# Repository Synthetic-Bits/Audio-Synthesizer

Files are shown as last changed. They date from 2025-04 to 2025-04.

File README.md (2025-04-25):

# MIDI Digital Synthesizer

The MIDI Digital Synthesizer is an embedded system capable of interpreting MIDI input signals and synthesizing the audio for the MIDI input. The project was developed as a final project for the University of Utah's ECE 5780: Embedded Systems class. While originally planned to be developed on an STM32F072 Discover board, the system now only works with a STM32H533RE NUCLEO board due to limitation's with the Discovery's flash memory as well as clock speed.

Code for the STM32F072 is present within this repository however, it should be noted that this code hasn't been integrated together and thus, doesn't really work in a cohesive system. That said, the code did represent effort that the Synthetic Bits put in to creating this project and thus, was included in this repository.

## Group Members

- Kenneth Gordon
- Bryant Watson
- Hayoung Im
- Adrian Sucahyo

## Features

The MIDI Digital Synthesizer has the following features:

### Hardware

Microcontroller:
 - STM32H533RE (NUCLEO)

Channels:
 - 7 PWM Channels
     - Sine
     - Triangle
     - Ramp
     - Square
 - 1 DAC
     - Noise

Individual Channel Control:
 - Gain Control
 - Toggleable Low Pass Filter

Master Control:
 - Master Volume Control

Output Speaker Driver:
 - LM1875 Based Class AB Amplifier
 - Up to 20 Watts Driver Capability

### Software

MIDI Interface:
 - MIDI Input
 - MIDI Output

Configurable Channel Waveforms
 - Sine
 - Triangle
 - Ramp
 - Square
 - Noise (restricted to channel 8)

Configurable Voice Channels
- Channels 1-7 capable of 8 voices
- Channels 8 capable of 1 voice

## System Block Diagram

### Software Block Diagram
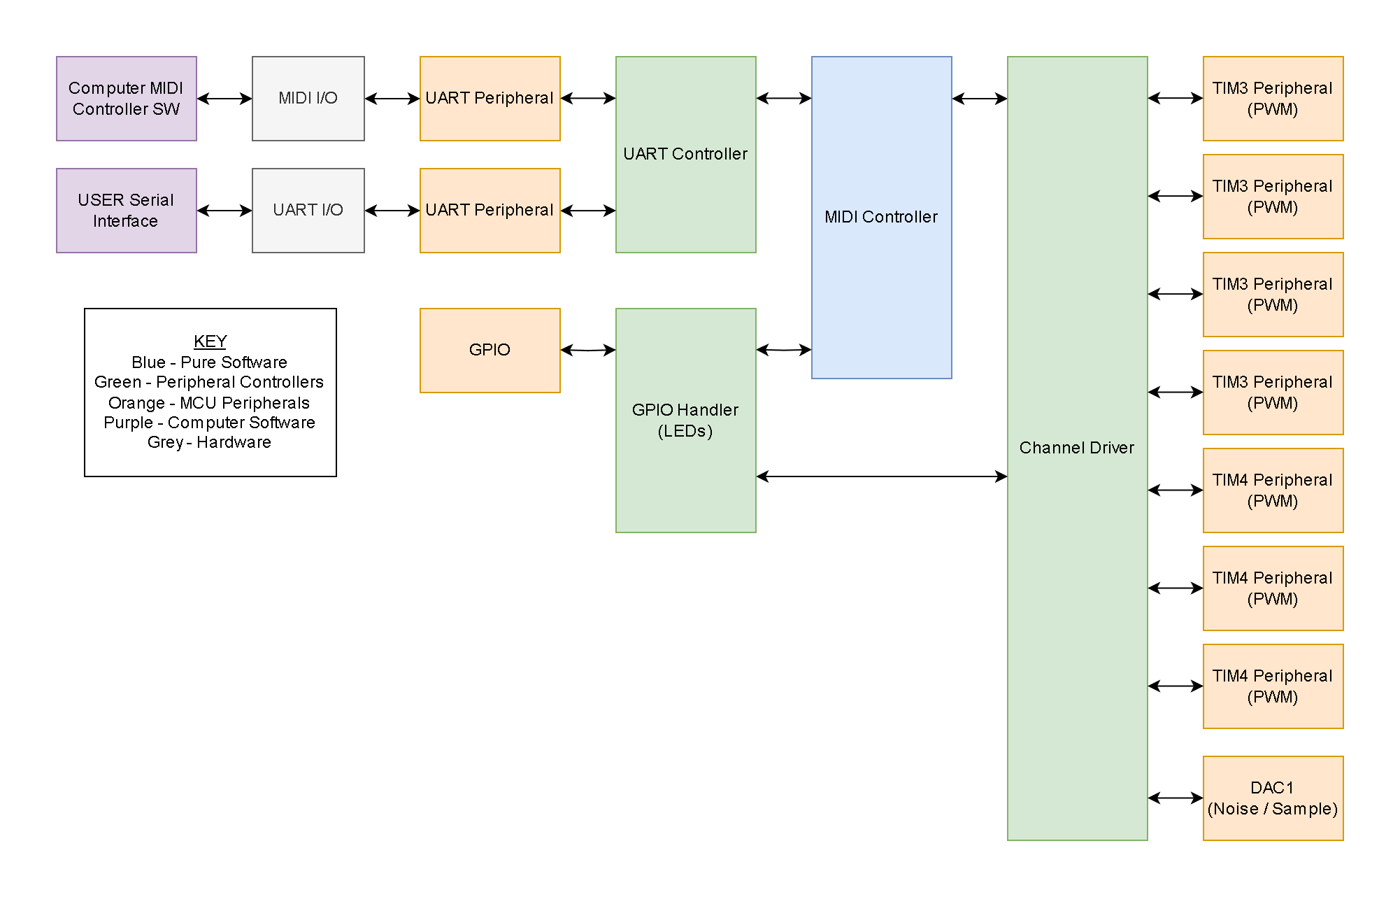
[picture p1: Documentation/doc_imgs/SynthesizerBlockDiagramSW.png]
Software Block Diagram


### Hardware Block Diagram
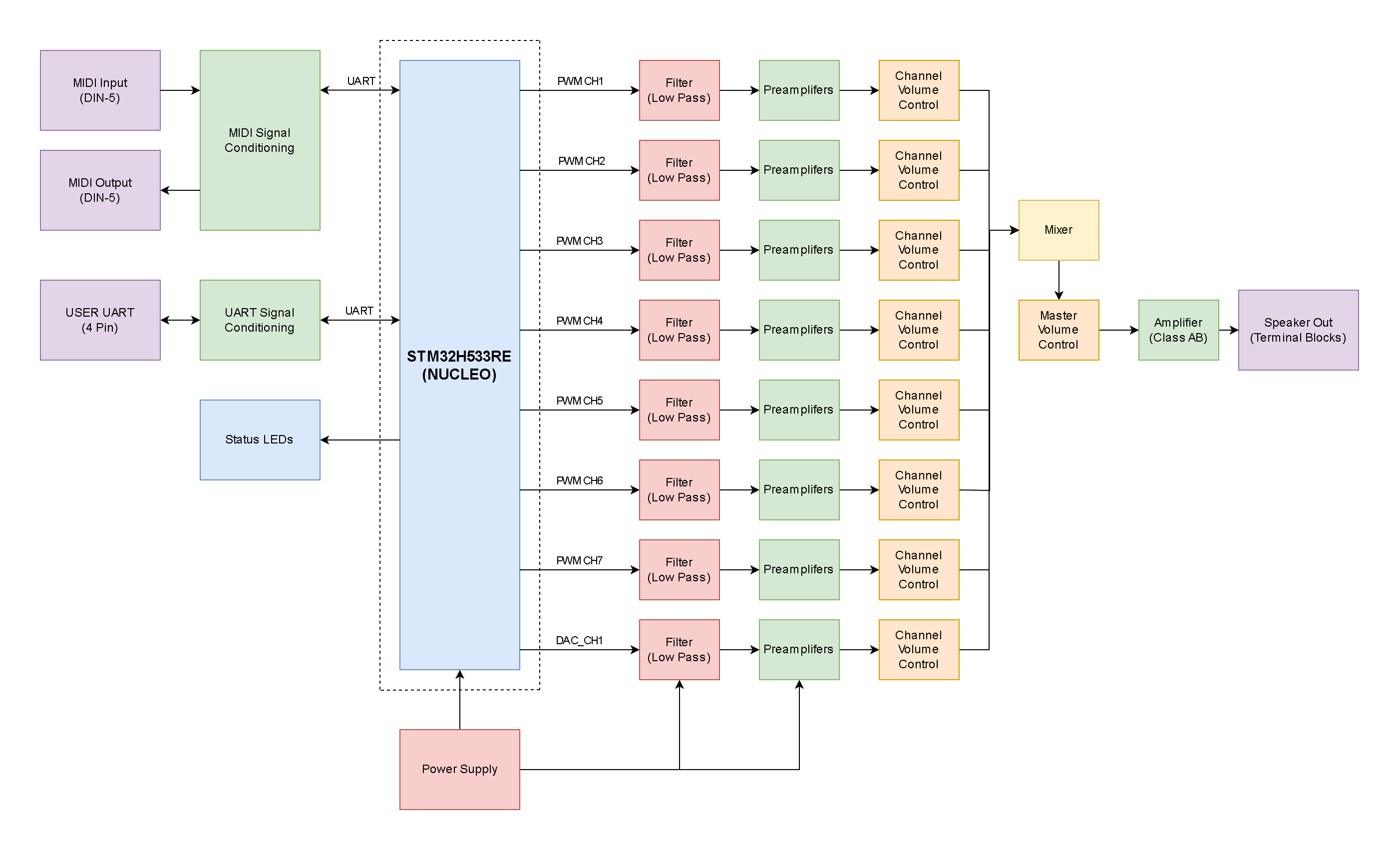
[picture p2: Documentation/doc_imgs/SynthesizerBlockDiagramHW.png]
Hardware Block Diagram


## Setup Guide

1. Put the STM32H533RE (NUCLEO) board (white) on the synthesizer PCB (black) as seen in the below diagrams.
2. Make sure that the jumper cable on the STM32H533RE (NUCLEO) board is set to the E5V to use external power for the board and PCB system.
3. Connect the +15V, GND, -15V, GND from the power supply to the board. Ensure that the power supply is off and to double check wiring is correct, before turning it on.
4. Connect an 8 Ohm speaker to the board.
5. Configure your low-pass filters as desired, per channel.
    - It's recommended to turn off the volume of each channel and set the master to 50%. 
    - Mix the audio as desired by turning up the volume per channel.
6. Connect the MIDI input to the PCB (either with a MIDI-compliant devices or through the pin headers)
    - If a computer is being used to stream MIDI over UART, you can use the provided Python code to stream a MIDI file to the synthesizer. See the below diagram for what pins should be connected.
7. Flash the NUCLEO board using the USB-C STLINK connector.
8. Send your MIDI input to the board. 
    - Mix each of the channels as well as the master channel as desired.
9. _Caution_, the class AB amplifier gets really hot, really quickly. Don't burn yourself or the board! 
    - It is highly recommended to have a large heat sink.

## Board 

### Front Panel

The leftmost connector on the board is the 8 Ohm speaker connector. The left port of this connector is the negative out and the right port is positive out. Refer to the figures above for wire connections.

The middle four connectors on the board control the positive and negative voltage inputs. The connector ports have the following order: GND, -15V, GND, and +15V. 

The rightmost two connectors are the MIDI IN and MIDI OUT connectors. The MIDI IN is used for sending midi commands to the microcontroller for synthesis. The MIDI IN line can connect to a compatible keyboard or computer for sound synthesis. The MIDI OUT is current not used but was included as future code can be written to send MIDI data to other devices from the synthesizer.

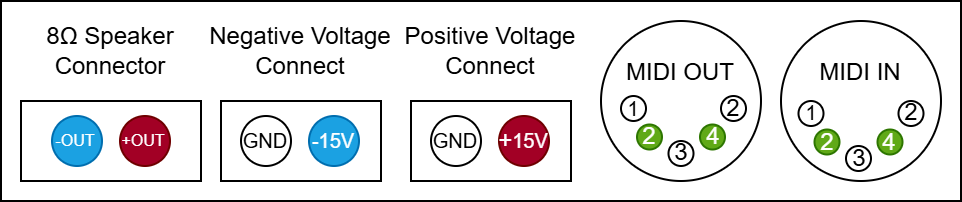
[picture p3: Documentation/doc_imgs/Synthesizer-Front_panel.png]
Front Panel Diagram


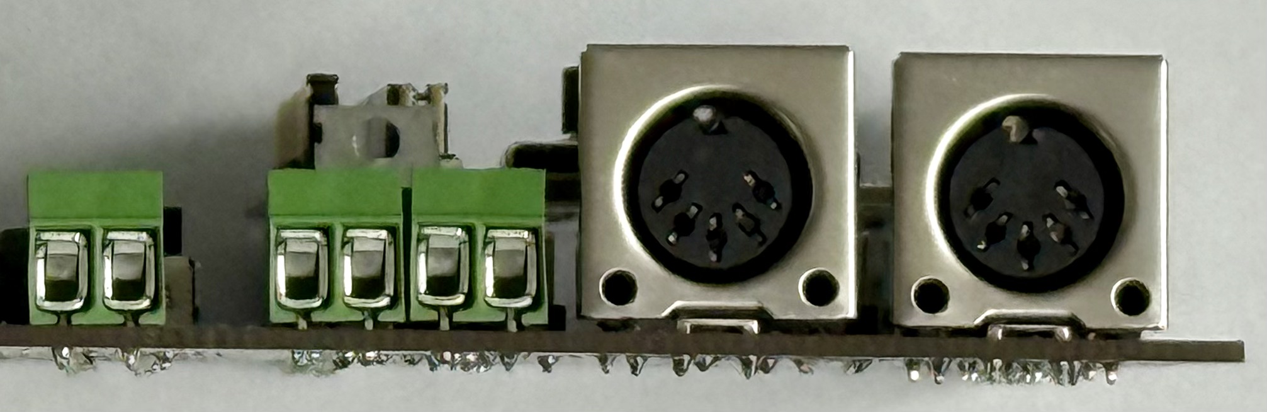
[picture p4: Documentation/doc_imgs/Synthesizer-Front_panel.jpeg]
Front Panel Image


### Top Down

The rightmost device is the the microcontroller board.  This board connects with the main synthesizer board. The blue dots are where a jumper is set.  The E5V connector is used to let the board know to use the external power. All other jumpers are standard and come with the NUCLEO board and the synthesizer board. The NUCLEO board contains a reset button to reset the program and a User button that is currently not used for the synthesizer. Furthermore, the programming for the NUCLEO board uses a USB type C connector on the bottom of the STM32 board. If the user wants to use USB power for testing or MIDI-OUT the user can change the jumper to 5V-STLINK.

The top left section of the board contains the modules for channels 1-8. Each module consists of a low-pass filter and amplifier buffer. The ON/OFF switch controls the low-pass filter. There is a volume nob that uses a potentiometer to control the channel's volume. If the more expensive potentiometers are not available, cheap potentiometers can be used. If cheaper potentiometers are used, the jumper must be moved down. 

The board also has a master channel that mixes and mixes the eight synthesizer channels. The master channel also contains a volume nob using a potentiometer.

There are pins on the main synthesizer board not mentioned above (such as the pins near the capacitors near the +15V and -15V.)  These pins are used for debugging the board.

On the bottom right of the synthesizer board, there are four pins near the MIDI IN that can also be used to send MIDI data from a computer using MIDI-over-UART. These pins are labeled 3V, RX, TX, and GND.

Front Panel Diagram

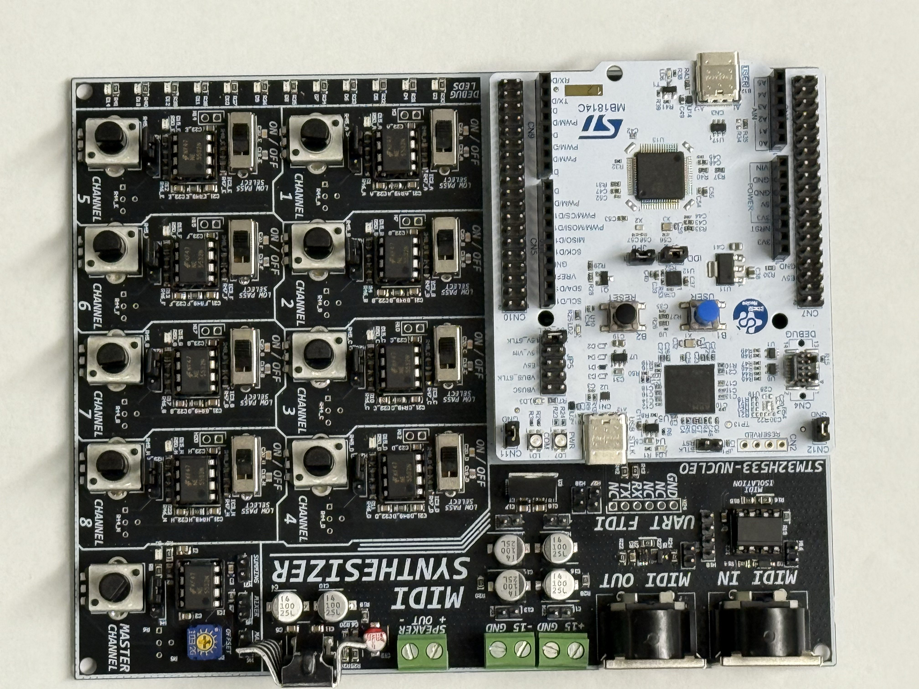
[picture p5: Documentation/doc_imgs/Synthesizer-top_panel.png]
Front Panel Image


## Board Schematic and PCB

### Schematics

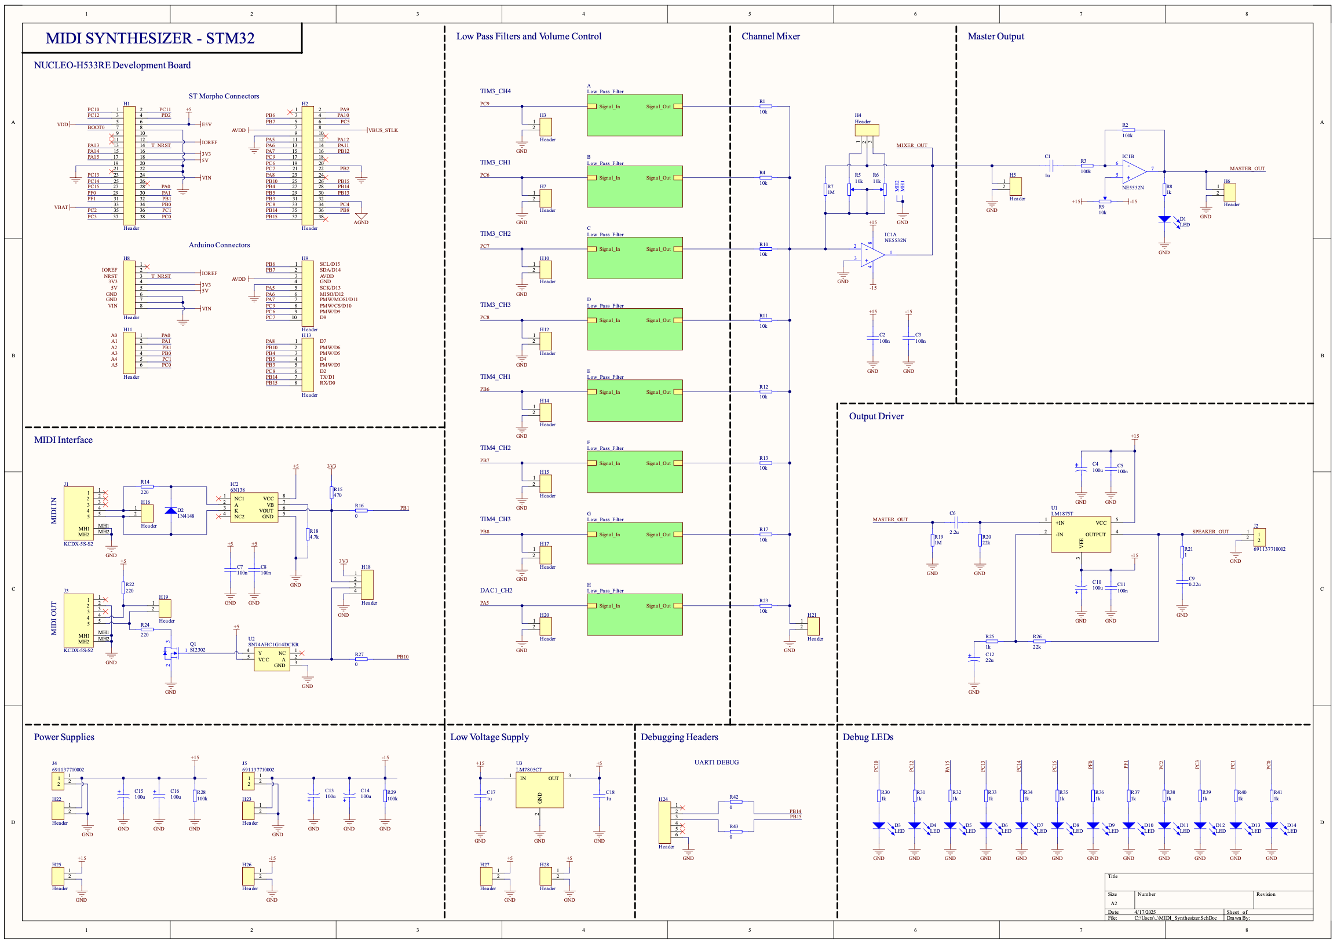
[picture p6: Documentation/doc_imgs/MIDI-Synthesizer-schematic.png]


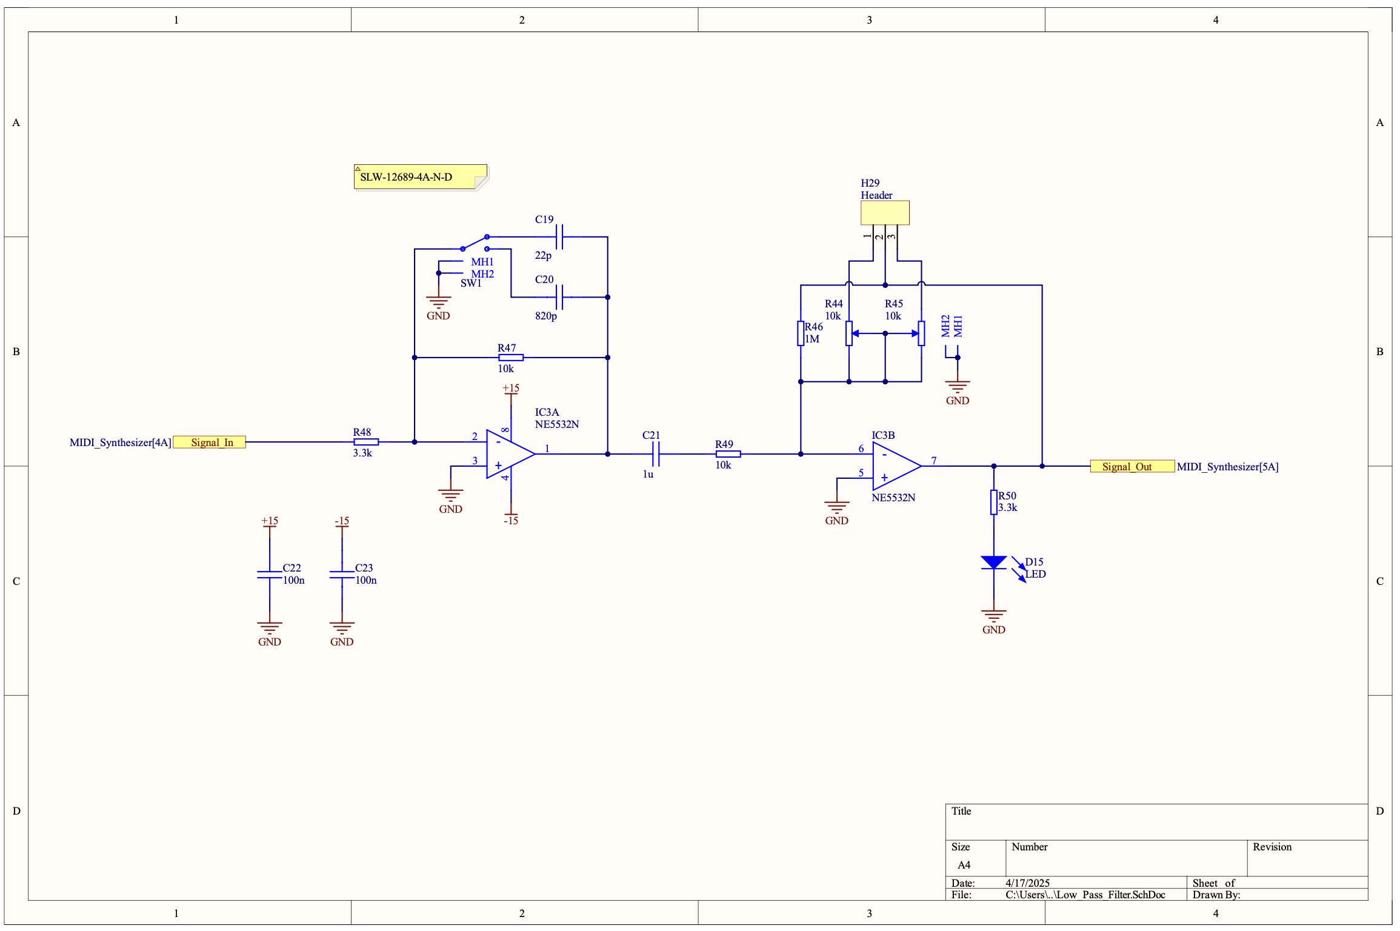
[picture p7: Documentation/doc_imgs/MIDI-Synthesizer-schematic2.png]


### PCB Design

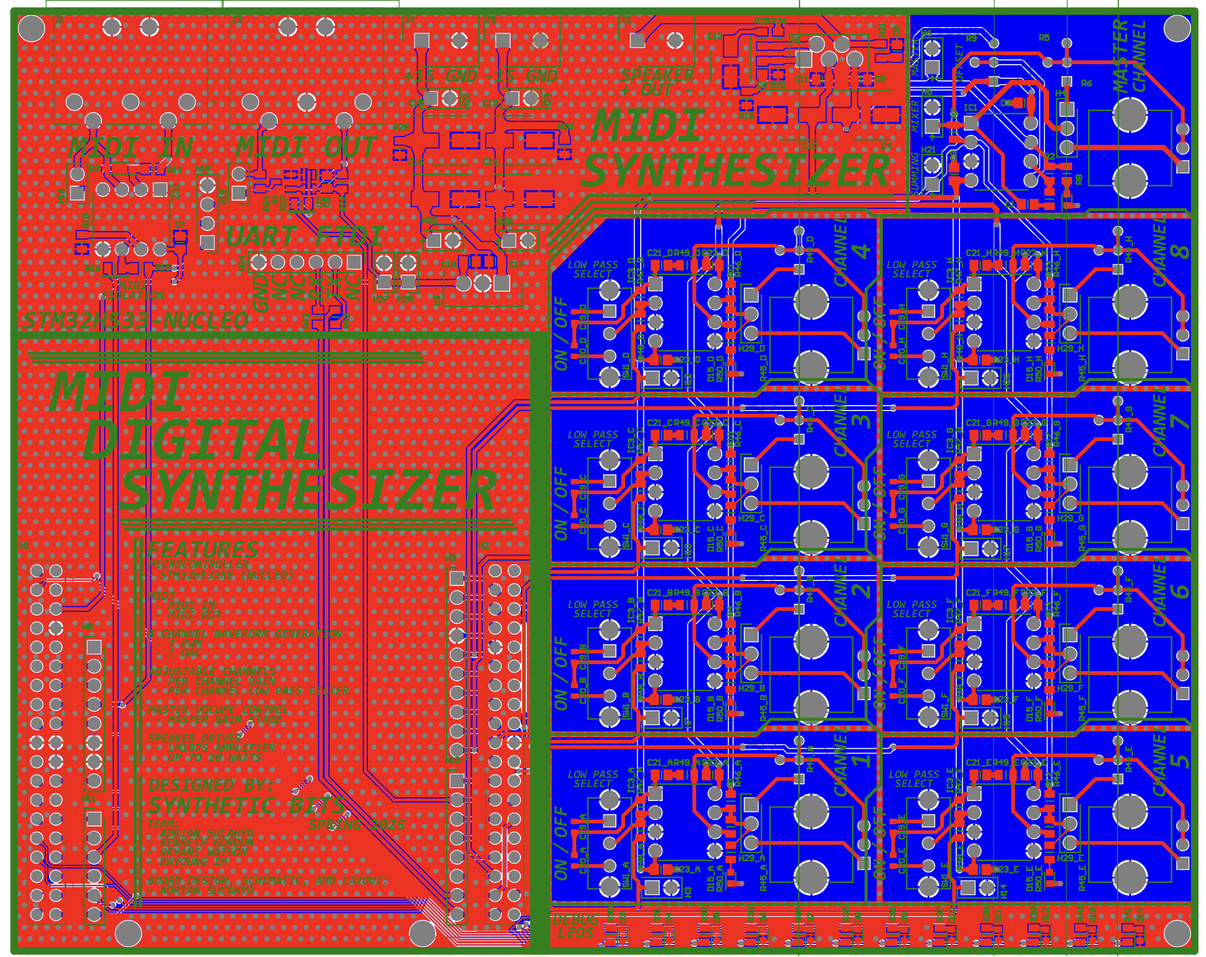
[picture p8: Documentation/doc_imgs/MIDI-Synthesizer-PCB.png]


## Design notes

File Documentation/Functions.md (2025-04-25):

## Src

- `channel_driver.c` – Controls STM32 timers and DAC to generate seven PWM waveform channels plus a noise channel, and provides functions to enable/disable channels, select waveforms, and manage volume and per-voice parameters.  

- `main.c` – Contains the main application entry point for the Audio-Synthesizer.

- `midi.c` – Parses incoming MIDI bytes, decodes MIDI events (note on/off, control changes, pitch bend), and drives the audio channels via the channel driver API.  

- `rcc.c` – Offers simple functions to enable RCC clocks for GPIOA–C, TIM2/3/4, DAC1, and USART1/3 on the STM32H5.  

- `sample_timer.c` – Configures TIM2 as the sample-rate timer and invokes a user-registered callback on each tick to update audio output.  

- `stm32h5xx_hal_msp.c` – Implements the HAL MSP init/de-init hooks, setting up system-level clocks, interrupt priorities, and debug interfaces.  

- `stm32h5xx_it.c` – Defines default ISR handlers for Cortex faults, SysTick, and peripheral interrupts, calling HAL or BSP callbacks as needed.

- `syscalls.c` – Provides minimal Newlib syscall stubs (_read, _write, _open) for bare-metal STM32, routing standard I/O through weak `__io_putchar`/`__io_getchar` hooks.  

- `sysmem.c` – Implements the `_sbrk()` syscall to grow the heap for `malloc` and friends, using linker symbols to prevent heap/stack collision. 

- `system_setup.c` – Implements the Error_Handler loop, configures the system clock (CSI + PLL, bus dividers, flash delay), initializes the instruction cache, and provides a full-assert failure hook.  

- `system_stm32h5xx.c` – Sets up the Error_Handler, system clock (PLL/CSI) and bus dividers, and initializes the instruction cache.  

- `uart.c` – Configures USART1 for user console I/O and USART3 for MIDI, implements interrupt-driven receive plus blocking send/receive routines, and offers a `printu()` helper for easy UART printing.

## Samples

- `attack_base.h` - Defines a 1024-entry short lookup table for the attack curve of the ADSR envelope for the synthesizer.

- `decay_base.h` - Defines a 1024-entry short lookup table for the decay portion of the ADSR envelope for the synthesizer.

- `modulation_base.h` - Defines a 16384-entry short lookup table for the modulation of the ADSR envelope for the synthesizer.

- `ramp_base.h` - Defines a 1024-entry unsigned short lookup table (generated from MATLAB) for the ramp waveform.

- `sine_base.h` - Defines a 1024-entry unsigned short lookup table (generated from MATLAB) for the sine waveform.

- `square_base.h` - Defines a 1024-entry unsigned short lookup table (generated from MATLAB) for the square waveform.

- `trig_base.h` - Defines a 1024-entry unsigned short lookup table (generated from MATLAB) for the trig waveform.

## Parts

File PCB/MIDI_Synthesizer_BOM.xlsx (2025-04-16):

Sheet: Assembly
Comment | Description | Designator | Quantity | Required QTY | To Order | Notes | Ordered
1u | Non Polarized Capacitor | C1, C17, C18, C21_A, C21_B, C21_C, C21_D, C21_E, C21_F, C21_G, C21_H | 11 | 44 | Yes | 50V | 100
100n | Non Polarized Capacitor | C2, C3, C5, C7, C8, C11, C22_A, C22_B, C22_C, C22_D, C22_E, C22_F, C22_G, C22_H, C23_A, C23_B, C23_C, C23_D, C23_E, C23_F, C23_G, C23_H | 22 | 88 | No
100u | Polarized Capacitor | C4, C10, C13, C14, C15, C16 | 6 | 24 | Yes | 50V | 30
2.2u | Polarized Capacitor | C6 | 1 | 4 | Yes | 50V | 10
0.22u | Polarized Capacitor | C9 | 1 | 4 | Yes | 50V | 25
22u | Polarized Capacitor | C12 | 1 | 4 | Yes | 50V | 10
22p | Non Polarized Capacitor | C19_A, C19_B, C19_C, C19_D, C19_E, C19_F, C19_G, C19_H | 8 | 32 | Yes | 50V | 100
820p | Non Polarized Capacitor | C20_A, C20_B, C20_C, C20_D, C20_E, C20_F, C20_G, C20_H | 8 | 32 | Yes | 50V | 100
LED | General Purpose LED | D1, D3, D4, D5, D6, D7, D8, D9, D10, D11, D12, D13, D14, D15_A, D15_B, D15_C, D15_D, D15_E, D15_F, D15_G, D15_H | 21 | 84 | No
1N4148 | 1N4148 General Purpose Switching Diode | D2 | 1 | 4 | No
Header | 38-Pin 2 Row Header | H1, H2 | 2 | 8 | Yes | Amazon
Header | 2-Pin Header | H3, H5, H6, H7, H10, H12, H14, H15, H16, H17, H19, H20, H21, H22, H23, H25, H26, H27, H28 | 19 | 76 | No
Header | 3-Pin Header | H4, H29_A, H29_B, H29_C, H29_D, H29_E, H29_F, H29_G, H29_H | 9 | 36 | No
Header | 8-Pin Header | H8, H13 | 2 | 8 | No
Header | 10-Pin Header | H9 | 1 | 4 | No
Header | 6-Pin Header | H11, H24 | 2 | 8 | No
Header | 4-Pin Header | H18 | 1 | 4 | No
NE5532N | Integrated Circuit | IC1, IC3_A, IC3_B, IC3_C, IC3_D, IC3_E, IC3_F, IC3_G, IC3_H | 9 | 36 | Yes | Stockroom
6N138 | Integrated Circuit | IC2 | 1 | 4 | Yes |  | 10
KCDX-5S-S2 | Connector | J1, J3 | 2 | 8 | Yes |  | 10
691137710002 | Connector | J2, J4, J5 | 3 | 12 | Yes | IEEE | 0
SI2302 | General Purpose N-Channel MOSFET | Q1 | 1 | 4 | No
10k | Resistor | R1, R4, R10, R11, R12, R13, R17, R23, R47_A, R47_B, R47_C, R47_D, R47_E, R47_F, R47_G, R47_H, R49_A, R49_B, R49_C, R49_D, R49_E, R49_F, R49_G, R49_H | 24 | 96 | No
100k | Resistor | R2, R3, R28, R29 | 4 | 16 | No
10k | Potentionmeter | R5, R9, R44_A, R44_B, R44_C, R44_D, R44_E, R44_F, R44_G, R44_H | 10 | 40 | Yes | Stockroom
10k | Potentionmeter | R6, R45_A, R45_B, R45_C, R45_D, R45_E, R45_F, R45_G, R45_H | 9 | 36 | Yes |  | 40
1M | Resistor | R7, R19, R46_A, R46_B, R46_C, R46_D, R46_E, R46_F, R46_G, R46_H | 10 | 40 | No
1k | Resistor | R8, R30, R31, R32, R33, R34, R35, R36, R37, R38, R39, R40, R41 | 13 | 52 | No
220 | Resistor | R14, R22, R24 | 3 | 12 | Yes |  | 100
470 | Resistor | R15 | 1 | 4 | No
0 | Resistor | R16, R27, R42, R43 | 4 | 16 | No
4.7k | Resistor | R18 | 1 | 4 | No
22k | Resistor | R20, R26 | 2 | 8 | Yes |  | 100
1 | Resistor | R21 | 1 | 4 | Yes |  | 100
1k | Resistor | R25 | 1 | 4 | No
3.3k | Resistor | R48_A, R48_B, R48_C, R48_D, R48_E, R48_F, R48_G, R48_H | 8 | 32 | No
3.3k | Resistor | R50_A, R50_B, R50_C, R50_D, R50_E, R50_F, R50_G, R50_H | 8 | 32 | No
Slide Switch 4 | Slide Switch | SW1_A, SW1_B, SW1_C, SW1_D, SW1_E, SW1_F, SW1_G, SW1_H | 8 | 32 | Yes |  | 40
LM1875T | Integrated Circuit | U1 | 1 | 4 | Yes |  | 6
SN74AHC1G14DCKR | Integrated Circuit | U2 | 1 | 4 | Yes |  | 10
LM7805CT | Integrated Circuit | U3 | 1 | 4 | Yes | Stockroom

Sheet: Sheet1
Comment | Description | Designator | Quantity | Required QTY | To Order | Notes | Ordered
1u | Non Polarized Capacitor | C1, C17, C18, C21_A, C21_B, C21_C, C21_D, C21_E, C21_F, C21_G, C21_H | 11 | 44 | Yes | 50V | 100
100n | Non Polarized Capacitor | C2, C3, C5, C7, C8, C11, C22_A, C22_B, C22_C, C22_D, C22_E, C22_F, C22_G, C22_H, C23_A, C23_B, C23_C, C23_D, C23_E, C23_F, C23_G, C23_H | 22 | 88 | No
100u | Polarized Capacitor | C4, C10, C13, C14, C15, C16 | 6 | 24 | Yes | 50V | 30
2.2u | Polarized Capacitor | C6 | 1 | 4 | Yes | 50V | 10
0.22u | Polarized Capacitor | C9 | 1 | 4 | Yes | 50V | 25
22u | Polarized Capacitor | C12 | 1 | 4 | Yes | 50V | 10
22p | Non Polarized Capacitor | C19_A, C19_B, C19_C, C19_D, C19_E, C19_F, C19_G, C19_H | 8 | 32 | Yes | 50V | 100
820p | Non Polarized Capacitor | C20_A, C20_B, C20_C, C20_D, C20_E, C20_F, C20_G, C20_H | 8 | 32 | Yes | 50V | 100
LED | General Purpose LED | D1, D3, D4, D5, D6, D7, D8, D9, D10, D11, D12, D13, D14, D15_A, D15_B, D15_C, D15_D, D15_E, D15_F, D15_G, D15_H | 21 | 84 | No
1N4148 | 1N4148 General Purpose Switching Diode | D2 | 1 | 4 | No
Header | 38-Pin 2 Row Header | H1, H2 | 2 | 8 | Yes | Amazon
Header | 2-Pin Header | H3, H5, H6, H7, H10, H12, H14, H15, H16, H17, H19, H20, H21, H22, H23, H25, H26, H27, H28 | 19 | 76 | No
Header | 3-Pin Header | H4, H29_A, H29_B, H29_C, H29_D, H29_E, H29_F, H29_G, H29_H | 9 | 36 | No
Header | 8-Pin Header | H8, H13 | 2 | 8 | No
Header | 10-Pin Header | H9 | 1 | 4 | No
Header | 6-Pin Header | H11, H24 | 2 | 8 | No
Header | 4-Pin Header | H18 | 1 | 4 | No
NE5532N | Integrated Circuit | IC1, IC3_A, IC3_B, IC3_C, IC3_D, IC3_E, IC3_F, IC3_G, IC3_H | 9 | 36 | Yes | Stockroom
6N138 | Integrated Circuit | IC2 | 1 | 4 | Yes |  | 10
KCDX-5S-S2 | Connector | J1, J3 | 2 | 8 | Yes |  | 10
691137710002 | Connector | J2, J4, J5 | 3 | 12 | Yes | IEEE | 0
SI2302 | General Purpose N-Channel MOSFET | Q1 | 1 | 4 | No
10k | Resistor | R1, R4, R10, R11, R12, R13, R17, R23, R47_A, R47_B, R47_C, R47_D, R47_E, R47_F, R47_G, R47_H, R49_A, R49_B, R49_C, R49_D, R49_E, R49_F, R49_G, R49_H | 24 | 96 | No
100k | Resistor | R2, R3, R28, R29 | 4 | 16 | No
10k | Potentionmeter | R5, R9, R44_A, R44_B, R44_C, R44_D, R44_E, R44_F, R44_G, R44_H | 10 | 40 | Yes | Stockroom
10k | Potentionmeter | R6, R45_A, R45_B, R45_C, R45_D, R45_E, R45_F, R45_G, R45_H | 9 | 36 | Yes |  | 40
1M | Resistor | R7, R19, R46_A, R46_B, R46_C, R46_D, R46_E, R46_F, R46_G, R46_H | 10 | 40 | No
1k | Resistor | R8, R30, R31, R32, R33, R34, R35, R36, R37, R38, R39, R40, R41 | 13 | 52 | No
220 | Resistor | R14, R22, R24 | 3 | 12 | Yes |  | 100
470 | Resistor | R15 | 1 | 4 | No
0 | Resistor | R16, R27, R42, R43 | 4 | 16 | No
4.7k | Resistor | R18 | 1 | 4 | No
22k | Resistor | R20, R26 | 2 | 8 | Yes |  | 100
1 | Resistor | R21 | 1 | 4 | Yes |  | 100
1k | Resistor | R25 | 1 | 4 | No
3.3k | Resistor | R48_A, R48_B, R48_C, R48_D, R48_E, R48_F, R48_G, R48_H | 8 | 32 | No
3.3k | Resistor | R50_A, R50_B, R50_C, R50_D, R50_E, R50_F, R50_G, R50_H | 8 | 32 | No
Slide Switch 4 | Slide Switch | SW1_A, SW1_B, SW1_C, SW1_D, SW1_E, SW1_F, SW1_G, SW1_H | 8 | 32 | Yes |  | 40
LM1875T | Integrated Circuit | U1 | 1 | 4 | Yes |  | 6
SN74AHC1G14DCKR | Integrated Circuit | U2 | 1 | 4 | Yes |  | 10
LM7805CT | Integrated Circuit | U3 | 1 | 4 | Yes | Stockroom

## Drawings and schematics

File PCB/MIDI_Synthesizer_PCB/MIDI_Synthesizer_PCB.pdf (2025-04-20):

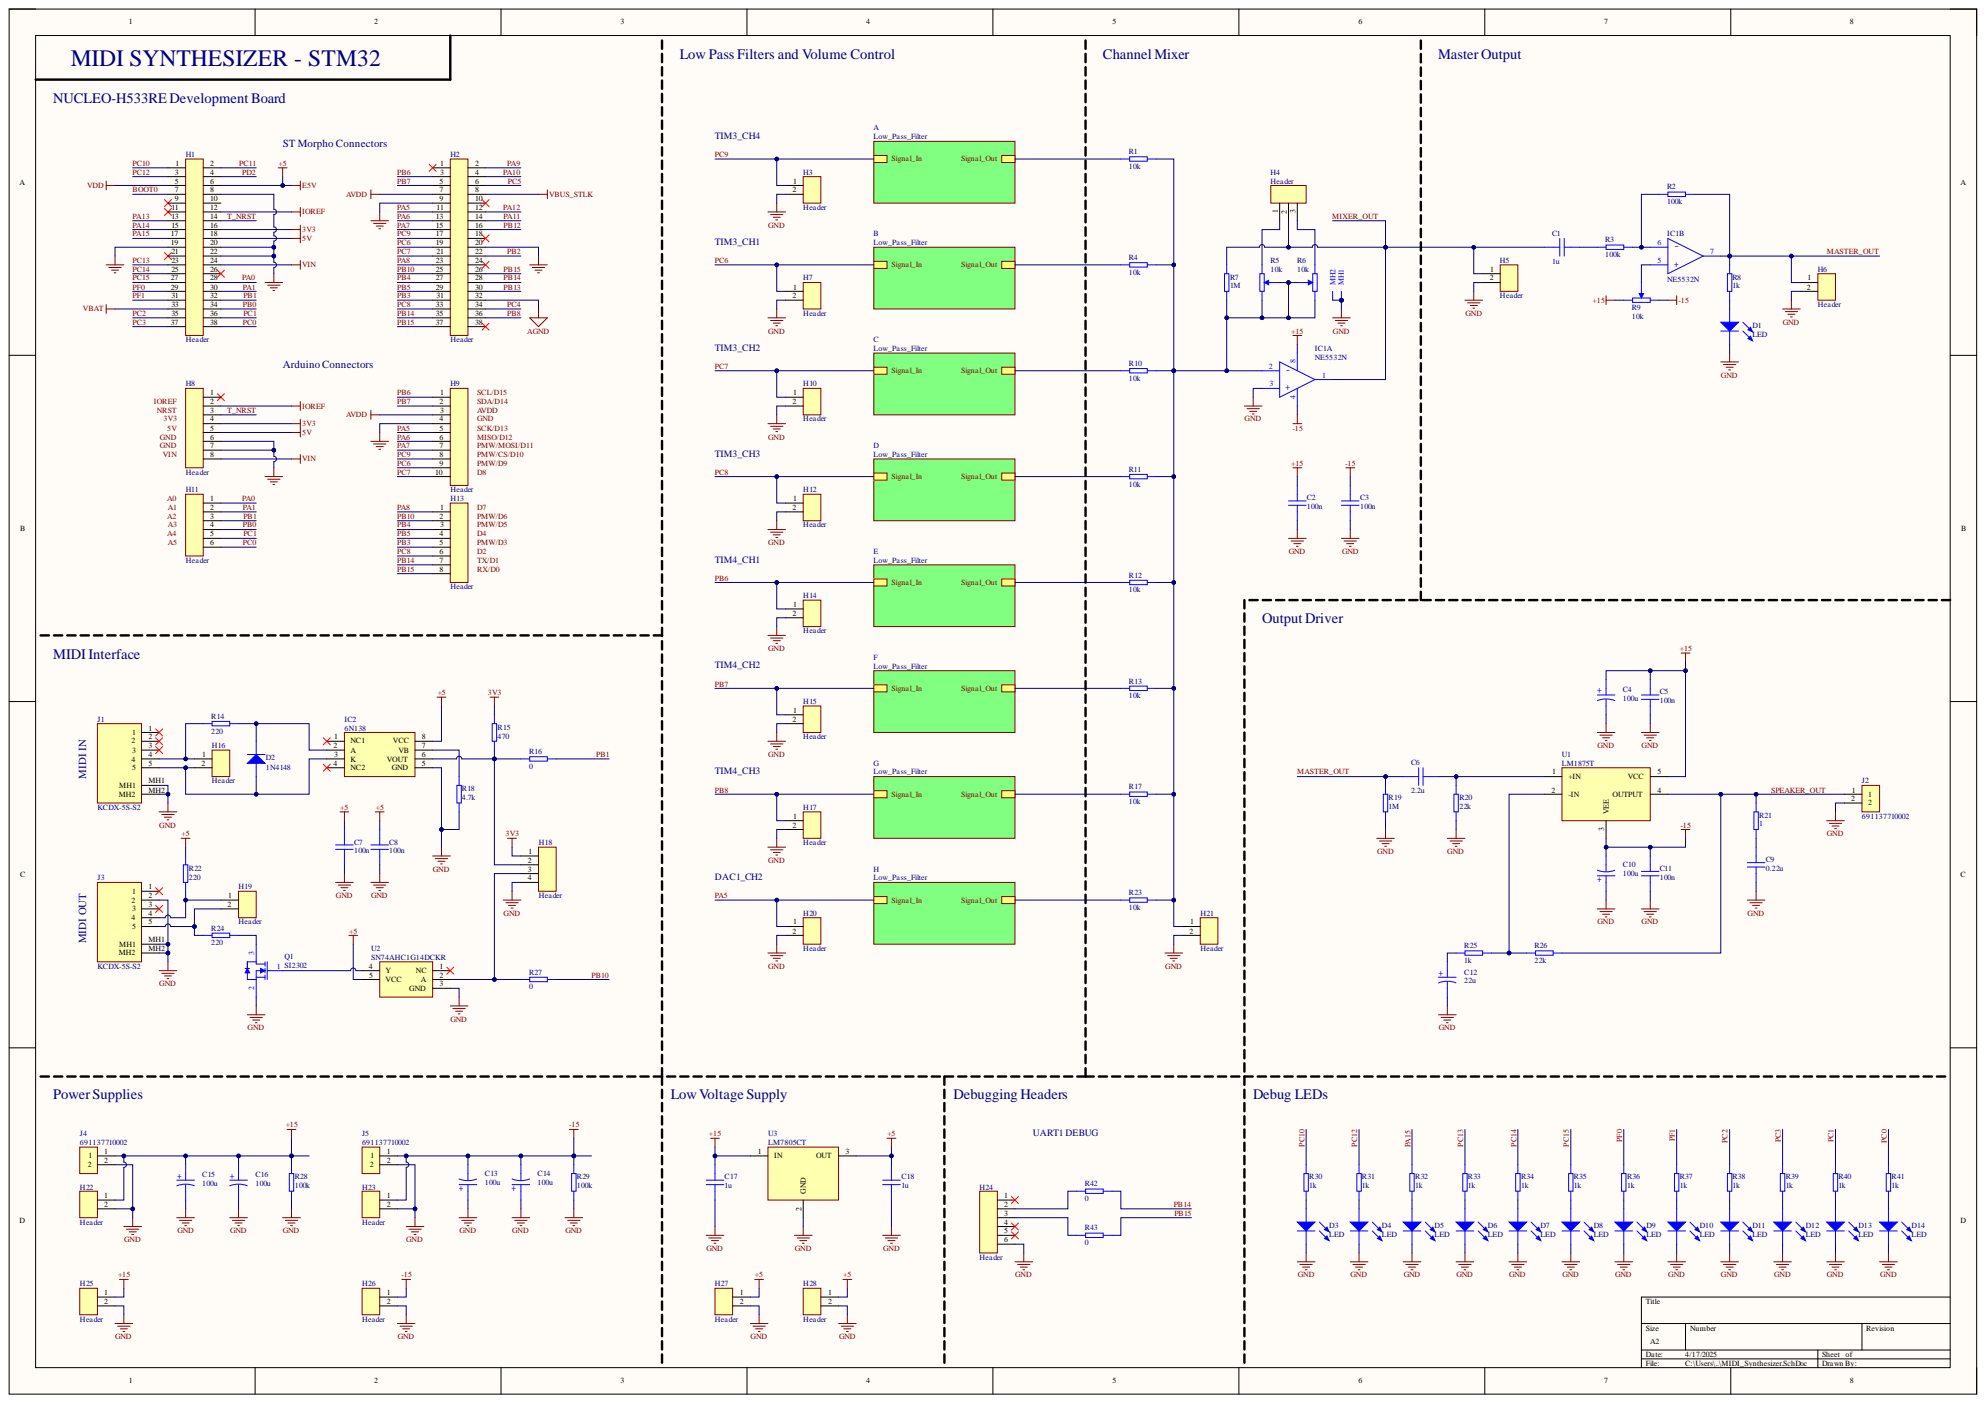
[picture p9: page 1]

Low Pass Filters and Volume Control

MIDI IN MIDI OUT

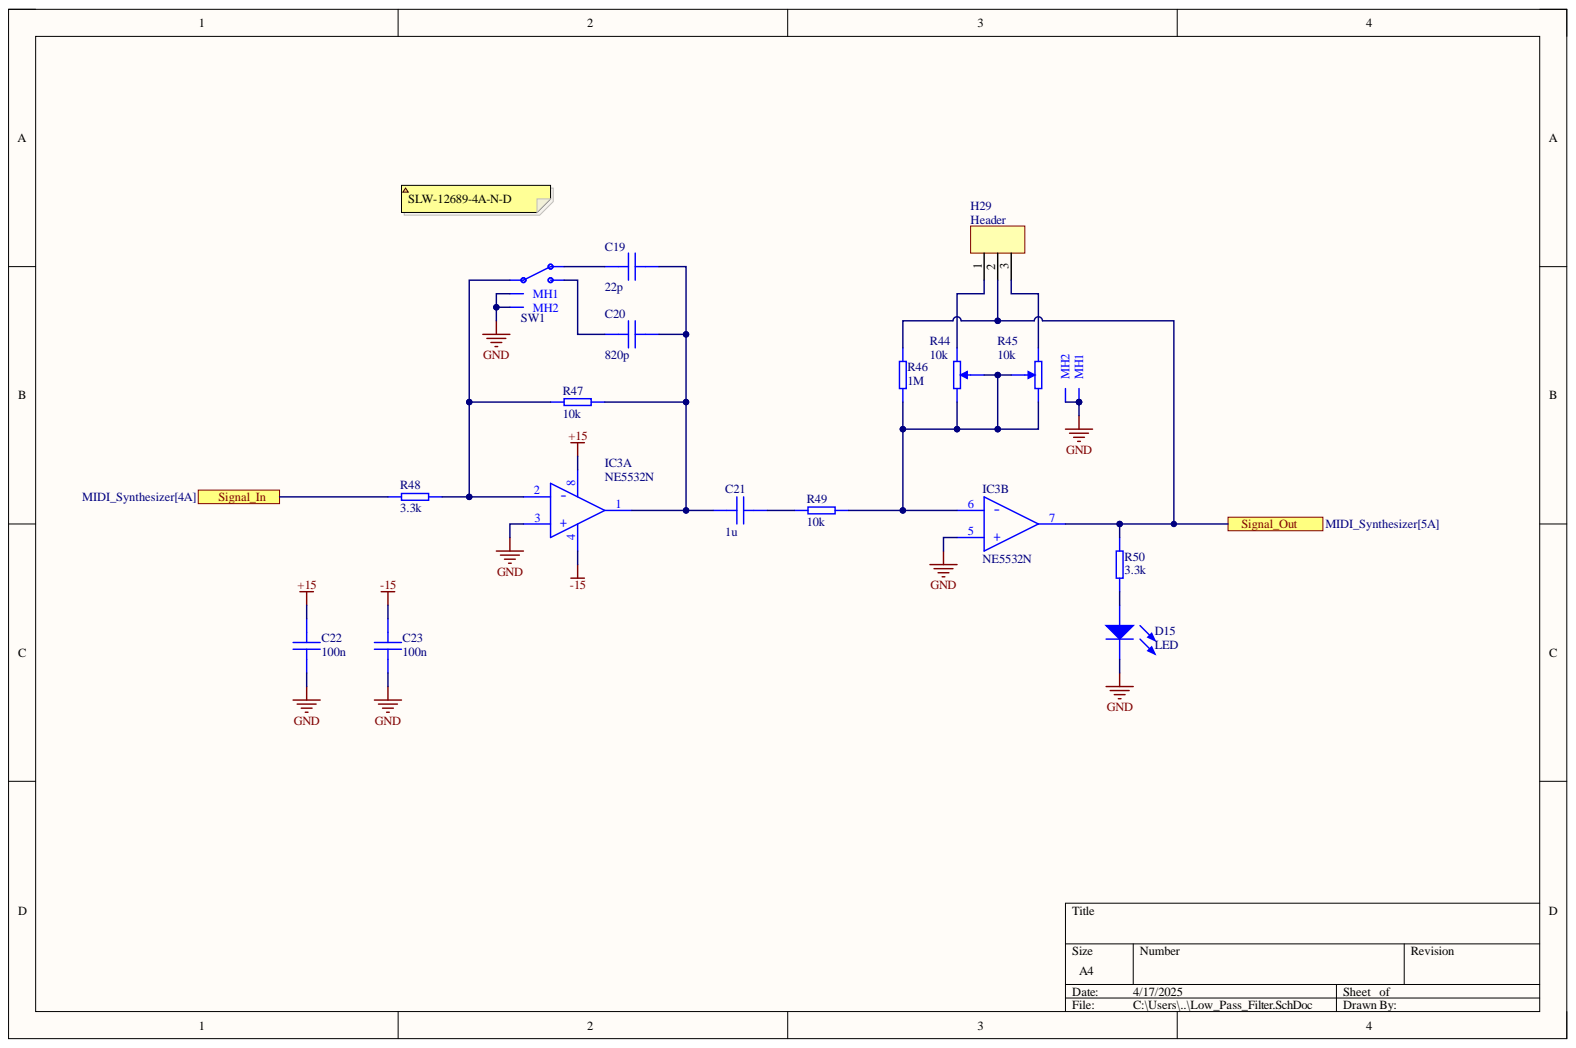
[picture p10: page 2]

Size A4 | Number | Revision

Date: 4/17/2025 | Sheet of
File: C:\Users\..\Low_Pass_Filter.SchDoc | Drawn By:

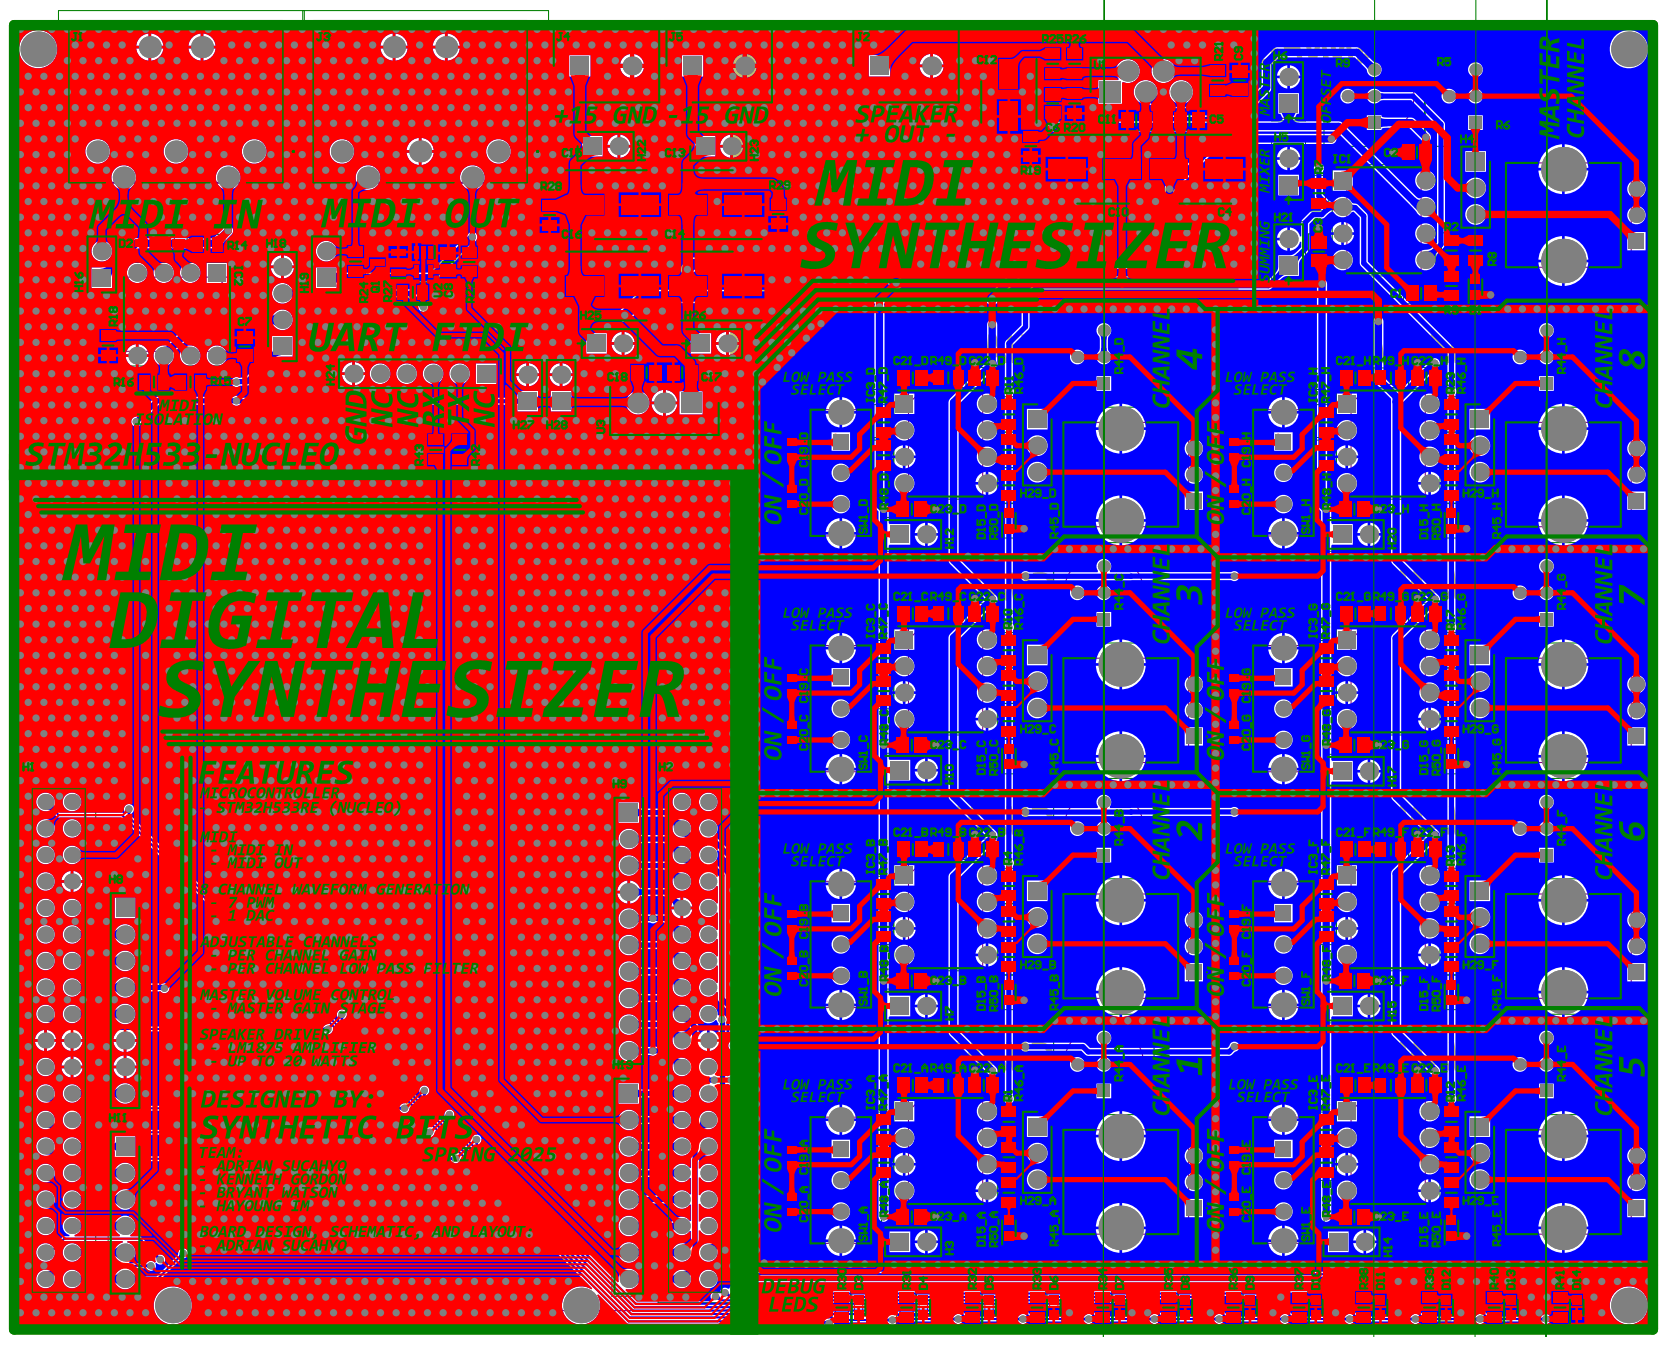
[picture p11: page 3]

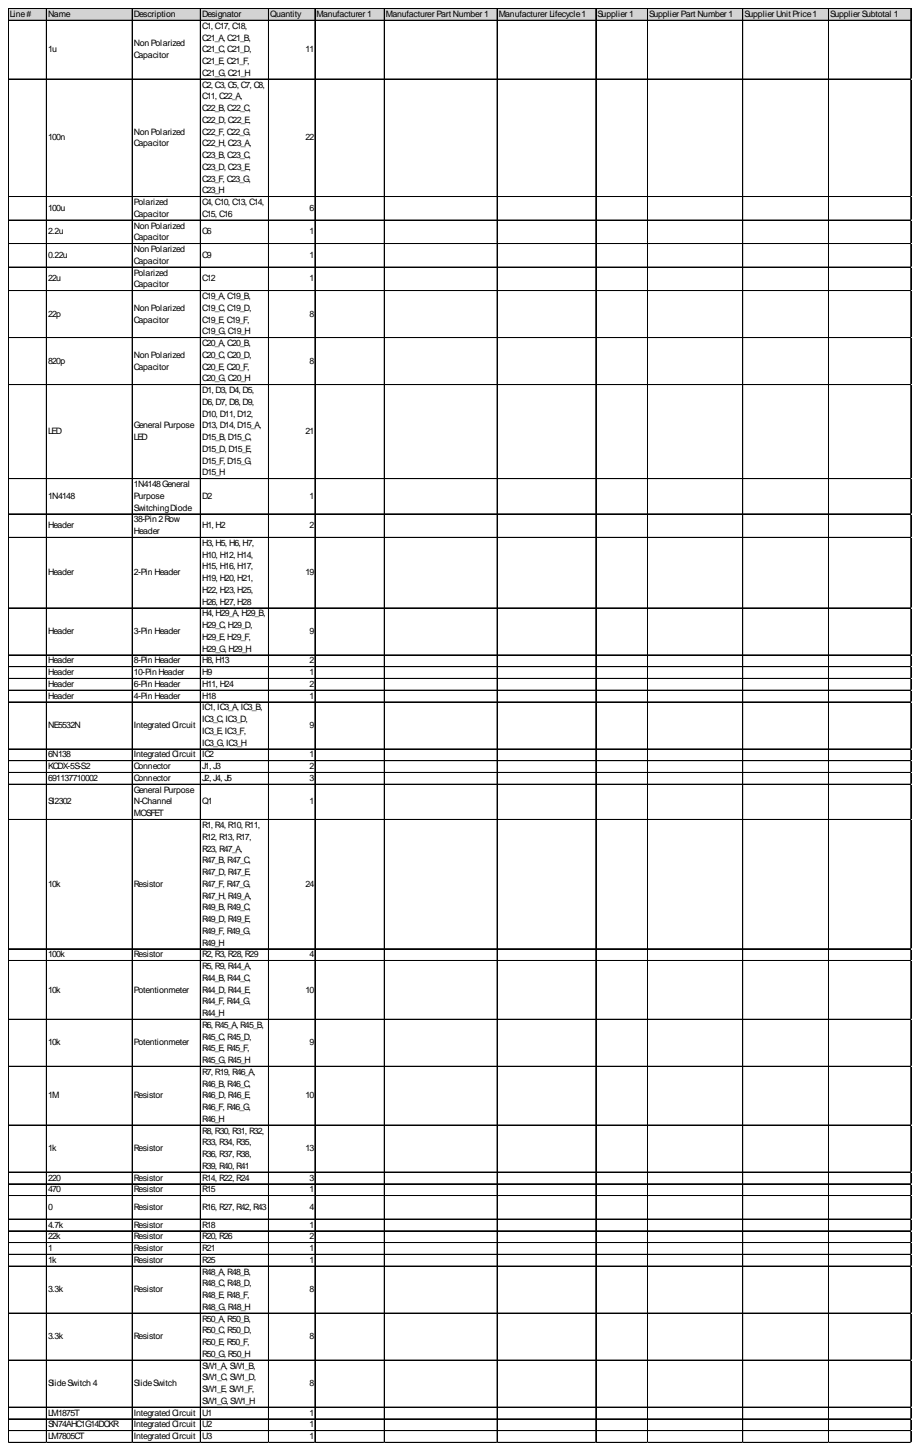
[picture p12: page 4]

Line# | Name | Description | Designator | Quantity | Manufacturer 1 | Manufacturer Part Number 1 | Manufacturer Lifecycle1 | Supplier 1 | Supplier Part Number 1 | Supplier Unit Price1 | Supplier Subtotal 1

1u | Non Polarized Capacitor | C1, C17, C18, C21_A, C21_B, C21_C, C21_D, C21_E, C21_F, C21_G, C21_H | 11

100n | Non Polarized Capacitor | C2, C3, C5, C7, C8, C11, C22_A, C22_B, C22_C, C22_D, C22_E, C22_F, C22_G, C22_H, C23_A, C23_B, C23_C, C23_D, C23_E, C23_F, C23_G, C23_H | 22

100u | Polarized Capacitor | C4, C10, C13, C14, C15, C16 | | 6

2.2u | Non Polarized Capacitor | C6 | | 1

0.22u | Non Polarized Capacitor | C9 | | 1

22u | Polarized Capacitor | C12 | | 1

22p | Non Polarized Capacitor | C19_A, C19_B, C19_C, C19_D, C19_E, C19_F, C19_G, C19_H | | 8

820p | Non Polarized Capacitor | C20_A, C20_B, C20_C, C20_D, C20_E, C20_F, C20_G, C20_H | | 8

LED | General Purpose LED | D1, D3, D4, D5, D6, D7, D8, D9, D10, D11, D12, D13, D14, D15_A, D15_B, D15_C, D15_D, D15_E, D15_F, D15_G, D15_H | 21

1N4148 | 1N4148General Purpose SwitchingDiode | D2 | | 1

Header | 38-Pin 2Row Header | H1, H2 | | 2

Header | 2-Pin Header | H3, H5, H6, H7, H10, H12, H14, H15, H16, H17, H19, H20, H21, H22, H23, H25, H26, H27, H28 | 19

Header | 3-Pin Header | H4, H29_A, H29_B, H29_C, H29_D, H29_E, H29_F, H29_G, H29_H | | 9

Header | 8-Pin Header | H8, H13 | | 2
Header | 10-Pin Header | H9 | | 1
Header | 6-Pin Header | H11, H24 | | 2
Header | 4-Pin Header | H18 | | 1
NE5532N | Integrated Circuit | IC1, IC3_A, IC3_B, IC3_C, IC3_D, IC3_E, IC3_F, IC3_G, IC3_H | | 9

6N138 | Integrated Circuit | IC2 | | 1
KCDX-5S-S2 | Connector | J1, J3 | | 2
691137710002 | Connector | J2, J4, J5 | | 3
SI2302 | General Purpose N-Channel MOSFET | Q1 | | 1

10k | Resistor | R1, R4, R10, R11, R12, R13, R17, R23, R47_A, R47_B, R47_C, R47_D, R47_E, R47_F, R47_G, R47_H, R49_A, R49_B, R49_C, R49_D, R49_E, R49_F, R49_G, R49_H | 24

100k | Resistor | R2, R3, R28, R29 | | 4
10k | Potentionmeter | R5, R9, R44_A, R44_B, R44_C, R44_D, R44_E, R44_F, R44_G, R44_H | 10

10k | Potentionmeter | R6, R45_A, R45_B, R45_C, R45_D, R45_E, R45_F, R45_G, R45_H | | 9

1M | Resistor | R7, R19, R46_A, R46_B, R46_C, R46_D, R46_E, R46_F, R46_G, R46_H | 10

1k | Resistor | R8, R30, R31, R32, R33, R34, R35, R36, R37, R38, R39, R40, R41 | 13

220 | Resistor | R14, R22, R24 | | 3
470 | Resistor | R15 | | 1

0 | Resistor | R16, R27, R42, R43 | | 4

4.7k | Resistor | R18 | | 1
22k | Resistor | R20, R26 | | 2
1 | Resistor | R21 | | 1
1k | Resistor | R25 | | 1
3.3k | Resistor | R48_A, R48_B, R48_C, R48_D, R48_E, R48_F, R48_G, R48_H | | 8

3.3k | Resistor | R50_A, R50_B, R50_C, R50_D, R50_E, R50_F, R50_G, R50_H | | 8

SlideSwitch 4 | SlideSwitch | SW1_A, SW1_B, SW1_C, SW1_D, SW1_E, SW1_F, SW1_G, SW1_H | | 8

LM1875T | Integrated Circuit | U1 | | 1
SN74AHC1G14DCKR | Integrated Circuit | U2 | | 1
LM7805CT | Integrated Circuit | U3 | | 1

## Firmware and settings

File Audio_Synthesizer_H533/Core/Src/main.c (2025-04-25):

/**
 ******************************************************************************
 * @file           : main.c
 * @brief          : Main program body
 * @authors        : Adrian Sucahyo, Kenneth Gordon, Bryant Watson,
 *                   and Hayoung Im
 ******************************************************************************
 * @attention
 *
 * Copyright (c) 2024 STMicroelectronics.
 * All rights reserved.
 *
 * This software is licensed under terms that can be found in the LICENSE file
 * in the root directory of this software component.
 * If no LICENSE file comes with this software, it is provided AS-IS.
 *
 ******************************************************************************
 */

/* Includes ------------------------------------------------------------------*/

#include "config.h"
#include "main.h"
#include "uart.h"
#include "midi.h"
#include <stm32h5xx_hal.h>

/* Private includes ----------------------------------------------------------*/

#include "sample_timer.h"
#include "channel_common.h"
#include "channel_driver.h"

/* Private typedef -----------------------------------------------------------*/

/* Private define ------------------------------------------------------------*/

// Define for configuring the UART tests
#define UART_INTERRUPT_TEST

#define MIDI_UART_SIZE (1024 * 8)

/* Private macro -------------------------------------------------------------*/

/* Private variables ---------------------------------------------------------*/

// UART Global Buffers
extern volatile int global_receive_buffer_index;
extern volatile uint8_t global_receive_buffer[GLOBAL_RECEIVE_BUFFER_SIZE];

// Flag for data received to idle
extern volatile uint8_t midi_data_ready_flag;

// What are these
extern volatile channel_state_t channel1_state, channel2_state, channel3_state, channel4_state, channel5_state, channel6_state, channel7_state, channel8_state;

static const uint16_t baud_rate = 31250;

// Channel Definitions
#define CHANNEL1_WAVE WAVEFORM_SQUARE
#define CHANNEL2_WAVE WAVEFORM_RAMP
#define CHANNEL3_WAVE WAVEFORM_TRIG
#define CHANNEL4_WAVE WAVEFORM_SINE
#define CHANNEL5_WAVE WAVEFORM_SQUARE
#define CHANNEL6_WAVE WAVEFORM_RAMP
#define CHANNEL7_WAVE WAVEFORM_TRIG
#define CHANNEL8_WAVE WAVEFORM_NOISE

/* Private function prototypes -----------------------------------------------*/

// Testing functions for UART
void test_USER_UART(void);
void test_MIDI_UART(void);

// Initialization functions
void init_sample_timer(void);
void init_channel_driver(void);

// Handler for when samples need to be updated
void sample_timer_handler(void);

// Synthesis functions
void midi_processer(void);
void start_audio_synthesis(void);
void stop_audio_synthesis(void);

/* Private user code ---------------------------------------------------------*/

/* ========================================================================== */
/*                                                                            */
/*        Demonstration Functions                                             */
/*                                                                            */
/* ========================================================================== */

/**
 * @brief This function tests the USER_UART peripheral to see if it is working as intended.
 * @param None
 * @retval None.
 */
void test_USER_UART()
{
#ifdef UART_INTERRUPT_TEST
  // Initialize the USER_UART peripheral (interrupt-mode)
  configure_USER_UART(115200, UART_ENABLE_INTERRUPTS, 2);

  // Send info using USER_UART
  send_USER_UART("Hello from the USER_UART peripheral!\n");

  // Loop until there are five bytes in the global_receive_buffer
  char buffer[7];
  while (1)
  {
    if (global_receive_buffer_index >= 5)
    {
      // Disable interrupts while we extract data from the buffer
      NVIC_DisableIRQ(USER_UART_IRQn);

      // Extract the data from the buffer
      for (int i = 0; i < 5; i++)
        buffer[i] = global_receive_buffer[i];
      buffer[5] = '\n';
      buffer[6] = '\x0';

      // Reset the buffer index, we got the data we need
      global_receive_buffer_index = 0;

      // Re-enable interrupts as we're done extracting data from the buffer
      NVIC_EnableIRQ(USER_UART_IRQn);
      break;
    }
  }

  // Test the printu() function to see if UART console output works
  printu(buffer);
#else
  // Initialize the USER_UART peripheral (blocking-mode)
  configure_USER_UART(115200, UART_DISABLE_INTERRUPTS, 2);

  // Send info using USER_UART
  send_USER_UART("Hello from the USER_UART peripheral!\n");

  // Receive info using USER_UART
  char buffer[7];
  receive_USER_UART_blocking(5, buffer);
  buffer[5] = '\n';
  buffer[6] = '\x0';

  // Test the printu() function to see if UART console output works
  printu(buffer);
#endif
}

/**
 * @brief This function tests the MIDI_UART peripheral to see if it is working as intended.
 * @param None
 * @retval None.
 */
void test_MIDI_UART()
{
#ifdef UART_INTERRUPT_TEST
  // Initialize the MIDI_UART peripheral (interrupt-mode)
  configure_MIDI_UART(115200, UART_ENABLE_INTERRUPTS, 2);

  // Send info using MIDI_UART
  send_MIDI_UART("Hello from the MIDI_UART peripheral!\n");

  // Loop until there are five bytes in the global_receive_buffer
  char buffer[7];
  while (1)
  {
    if (global_receive_buffer_index >= 5)
    {
      // Disable interrupts while we extract data from the buffer
      NVIC_DisableIRQ(MIDI_UART_IRQn);

      // Extract the data from the buffer
      for (int i = 0; i < 5; i++)
        buffer[i] = global_receive_buffer[i];
      buffer[5] = '\n';
      buffer[6] = '\x0';

      // Reset the buffer index, we got the data we need
      global_receive_buffer_index = 0;

      // Re-enable interrupts as we're done extracting data from the buffer
      NVIC_EnableIRQ(MIDI_UART_IRQn);
      break;
    }
  }

  // Echo the received data back using MIDI_UART
  send_MIDI_UART(buffer);
#else
  // Initialize the MIDI_UART peripheral (blocking-mode)
  configure_MIDI_UART(115200, UART_DISABLE_INTERRUPTS, 2);

  // Send info using MIDI_UART
  send_MIDI_UART("Hello from the MIDI_UART peripheral!\n");

  // Receive info using MIDI_UART
  char buffer[7];
  receive_MIDI_UART_blocking(5, buffer);
  buffer[5] = '\n';
  buffer[6] = '\x0';

  // Echo the received data back using MIDI_UART
  send_MIDI_UART(buffer);
#endif
}

/* ========================================================================== */
/*                                                                            */
/*        Callback Handlers                                                   */
/*                                                                            */
/* ========================================================================== */

/**
 * @brief Sample timer callback handler - invoked when sample timer asserts
 * @param None
 * @retval None.
 */
void sample_timer_handler()
{
  channel_update_all();
}

/* ========================================================================== */
/*                                                                            */
/*        Initialization and Control Functions                                */
/*                                                                            */
/* ========================================================================== */

/**
 * @brief Initialize all the necessary components for the channel driver
 */
void init_sample_timer()
{
  // Configure and start the sample timer
  sample_timer_register_cb(sample_timer_handler); // Register the Sample Timer Callback
  sample_timer_init();
}

/**
 * @brief Initialize all the necessary components for the channel driver
 * @param None
 */
void init_channel_driver()
{
  // Channels 1-7
  channel_timer_init();

  // Channel 1 Settings
  channel_enable(CHANNEL1);
  channel_set_waveform(CHANNEL1, CHANNEL1_WAVE);
  channel_volume(CHANNEL1, 127);

  // Channel 2 Settings
  channel_enable(CHANNEL2);
  channel_set_waveform(CHANNEL2, CHANNEL2_WAVE);
  channel_volume(CHANNEL2, 127);

  // Channel 3 Settings
  channel_enable(CHANNEL3);
  channel_set_waveform(CHANNEL3, CHANNEL3_WAVE);
  channel_volume(CHANNEL3, 127);

  // Channel 4 Settings
  channel_enable(CHANNEL4);
  channel_set_waveform(CHANNEL4, CHANNEL4_WAVE);
  channel_volume(CHANNEL4, 127);

  // Channel 5 Settings
  channel_enable(CHANNEL5);
  channel_set_waveform(CHANNEL5, CHANNEL5_WAVE);
  channel_volume(CHANNEL5, 127);

  // Channel 6 Settings
  channel_enable(CHANNEL6);
  channel_set_waveform(CHANNEL6, CHANNEL6_WAVE);
  channel_volume(CHANNEL6, 127);

  // Channel 7 Settings
  channel_enable(CHANNEL7);
  channel_set_waveform(CHANNEL7, CHANNEL7_WAVE);
  channel_volume(CHANNEL7, 127);

  // Channel 8 Settings
  channel_enable(CHANNEL8);
  channel_set_waveform(CHANNEL8, CHANNEL8_WAVE);
  channel_volume(CHANNEL8, 127);
}

/**
 * @brief Start the overall audio synthesis
 */
void start_audio_synthesis()
{
  // Start the sample timer (advance the sampled waveforms)
  sample_timer_start();
}

/**
 * @brief Stop the overall audio synthesis
 */
void stop_audio_synthesis()
{
  // Stop the sample timer (advance the sampled waveforms)
  sample_timer_stop();
}

/* ========================================================================== */
/*                                                                            */
/*        Main Loop                                                           */
/*                                                                            */
/* ========================================================================== */

/**
 * @brief  The application entry point.
 * @retval int
 */
int main(void)
{
  // Configure the System Clock
  SystemClock_Config();

  // Enable the Instruction Caching
  MX_ICACHE_Init();

  // == AUDIO SETUP ==
  init_sample_timer();
  init_channel_driver();

  // -== UART MIDI SETUP ==
  configure_MIDI_UART(baud_rate, UART_ENABLE_INTERRUPTS, MIDI_IRQ_PRIORITY);

  // -== AUDIO SYNTHESIS & MIDI PROCESSING ==--
  start_audio_synthesis();

  midi_channel_voice_init();

  // Main Processing Loop
  while (1)
  {
    midi_process();
  }
}

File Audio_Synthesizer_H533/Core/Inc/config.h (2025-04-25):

/**
 ******************************************************************************
 * @file           : config.h
 * @brief          : Pin and Component Config Header
 * @authors        : Adrian Sucahyo, Kenneth Gordon, Bryant Watson,
 *                   and Hayoung Im
 ******************************************************************************
 */

#include "main.h"

#ifndef _CONFIG_H_
#define _CONFIG_H_

/* ========================================================================== */
/*                                                                            */
/*    Sample Timer Definitions                                                */
/*                                                                            */
/* ========================================================================== */

#define SAMPLE_TIMER TIM2
#define SAMPLE_TIMER_IRQ TIM2_IRQn // Ensure to update the IRQ cb if necessary

/* ========================================================================== */
/*                                                                            */
/*    Channel 1 to 4 Definitions                                              */
/*                                                                            */
/* ========================================================================== */

#define CHANNEL1_4_TIMER TIM3 // Ensure to update the RCC if necessary

#define CHANNEL1_4_GPIO_PORT GPIOC
#define CHANNEL1_GPIO_PIN GPIO_PIN_9 // PC9
#define CHANNEL2_GPIO_PIN GPIO_PIN_6 // PC6
#define CHANNEL3_GPIO_PIN GPIO_PIN_7 // PC7
#define CHANNEL4_GPIO_PIN GPIO_PIN_8 // PC8

/* ========================================================================== */
/*                                                                            */
/*    Channel 5 to 7 Definitions                                              */
/*                                                                            */
/* ========================================================================== */

#define CHANNEL5_7_TIMER TIM4 // Ensure to update the RCC if necessary

#define CHANNEL5_7_GPIO_PORT GPIOB
#define CHANNEL5_GPIO_PIN GPIO_PIN_6 // PB6
#define CHANNEL6_GPIO_PIN GPIO_PIN_7 // PB7
#define CHANNEL7_GPIO_PIN GPIO_PIN_8 // PB8

/* ========================================================================== */
/*                                                                            */
/*    Channel 8 Definitions                                                   */
/*                                                                            */
/* ========================================================================== */

#define CHANNEL8_DAC DAC1 // Ensure to update the RCC if necessary
#define CHANNEL8_DAC_CH DAC1_CHANNEL_2

#define CHANNEL8_GPIO_PORT GPIOA
#define CHANNEL8_GPIO_PIN GPIO_PIN_5 // PA5

/* ========================================================================== */
/*                                                                            */
/*    UART Definitions                                                        */
/*                                                                            */
/* ========================================================================== */

#define USER_UART USART1
#define USER_UART_PORT GPIOB
#define USER_UART_TX_PIN GPIO_PIN_14 // PB14
#define USER_UART_RX_PIN GPIO_PIN_15 // PB15
#define USER_UART_IRQn USART1_IRQn

#define MIDI_UART USART3
#define MIDI_UART_PORT GPIOB
#define MIDI_UART_TX_PIN GPIO_PIN_10 // PB10
#define MIDI_UART_RX_PIN GPIO_PIN_1  // PB1
#define MIDI_UART_IRQn USART3_IRQn
#define MIDI_IRQ_PRIORITY 1

/* ========================================================================== */
/*                                                                            */
/*    DEBUG LED Definitions                                                   */
/*                                                                            */
/* ========================================================================== */

#define DEBUG_LED_PORT1 GPIOC
#define DEBUG_LED_PORT2 GPIOA
#define DEBUG_LED_PORT3 GPIOF

#define DEBUG_LED0_PIN GPIO_PIN_10 // PC10
#define DEBUG_LED1_PIN GPIO_PIN_12 // PC11
#define DEBUG_LED2_PIN GPIO_PIN_15 // PA15
#define DEBUG_LED3_PIN GPIO_PIN_13 // PC13
#define DEBUG_LED4_PIN GPIO_PIN_14 // PC14
#define DEBUG_LED5_PIN GPIO_PIN_15 // PC15
#define DEBUG_LED6_PIN GPIO_PIN_0  // PF0
#define DEBUG_LED7_PIN GPIO_PIN_1  // PF1
#define DEBUG_LED8_PIN GPIO_PIN_2  // PC2
#define DEBUG_LED9_PIN GPIO_PIN_3  // PC3
#define DEBUG_LED10_PIN GPIO_PIN_1 // PC1
#define DEBUG_LED11_PIN GPIO_PIN_0 // PC0

#endif /* _CONFIG_H_ */

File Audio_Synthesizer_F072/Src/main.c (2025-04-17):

/**
 ******************************************************************************
 * @file           : main.c
 * @brief          : Main program body
 ******************************************************************************
 * @attention
 *
 * Copyright (c) 2024 STMicroelectronics.
 * All rights reserved.
 *
 * This software is licensed under terms that can be found in the LICENSE file
 * in the root directory of this software component.
 * If no LICENSE file comes with this software, it is provided AS-IS.
 *
 ******************************************************************************
 */
/* Includes ------------------------------------------------------------------*/

#include "main.h"
#include <stm32f0xx_hal.h>

/* Private includes ----------------------------------------------------------*/

#include "uart.h"
#include "midi.h"
#include "gpio.h"

#include "sample_timer.h"
#include "channel_common.h"
#include "channel1_4_timer.h"

/* Private typedef -----------------------------------------------------------*/

/* Private define ------------------------------------------------------------*/

/* Private macro -------------------------------------------------------------*/

/* Private variables ---------------------------------------------------------*/

extern volatile channel_state_t channel1_state, channel2_state, channel3_state, channel4_state;
extern volatile int globalReceiveBufferIndex;
extern volatile char globalReceiveBuffer[];

/* Private function prototypes -----------------------------------------------*/

/* Private user code ---------------------------------------------------------*/

void sample_timer_handler(uint16_t counter)
{
  channel1_4_update();
}

void checkpoint_1()
{
  // Create a constant that holds the size of UART packets
  const int packetSize = 8;

  // Configure the LEDs
  initializeLEDs();

  // Configure the UART3 peripheral to get MIDI signals
  configureUART3(115200, UART_ENABLE_INTERRUPTS, 2);

  // Loop forever
  while (1)
  {
    if (globalReceiveBufferIndex >= packetSize)
    {
      // Disable UART interrupts while we process the packet
      NVIC_DisableIRQ(USART3_4_IRQn);

      // Reset the global receive buffer's index
      globalReceiveBufferIndex = 0;

      // Read from the global receive buffer
      char data[packetSize];
      for (int i = 0; i < packetSize; i++)
        data[i] = globalReceiveBuffer[i];

      // Process the UART data as MIDI
      setup_midi();
      set_midi(data);

      // Enable UART interrupts again as the data has been copied and processed
      NVIC_EnableIRQ(USART3_4_IRQn);
    }
  }
}

void checkpoint_2()
{
  // ==== SAMPLE TIMER ====
  sample_timer_register_cb(sample_timer_handler); // Register the Sample Timer Callback
  sample_timer_init();
  
  // ==== OUTPUT CHANNELS ====
  // Channels 1 - 4
  channel1_4_timer_init();

  // Channel 1 Settings
  channel1_4_enable(CHANNEL1);
  channel1_4_set_waveform(CHANNEL1, WAVEFORM_SINE);
  channel1_4_on_off(CHANNEL1, 1);
  channel1_4_frequency(CHANNEL1, 100);
  channel1_4_volume(CHANNEL1, 127);

  // Channel 2 Settings
  channel1_4_enable(CHANNEL2);
  channel1_4_set_waveform(CHANNEL2, WAVEFORM_TRIG);
  channel1_4_on_off(CHANNEL2, 1);
  channel1_4_frequency(CHANNEL2, 100);
  channel1_4_volume(CHANNEL2, 127);

  // Channel 3 Settings
  channel1_4_enable(CHANNEL3);
  channel1_4_set_waveform(CHANNEL3, WAVEFORM_RAMP);
  channel1_4_on_off(CHANNEL3, 1);
  channel1_4_frequency(CHANNEL3, 100);
  channel1_4_volume(CHANNEL3, 127);

  // Channel 4 Settings
  channel1_4_enable(CHANNEL4);
  channel1_4_set_waveform(CHANNEL4, WAVEFORM_SQUARE);
  channel1_4_on_off(CHANNEL4, 1);
  channel1_4_frequency(CHANNEL4, 100);
  channel1_4_volume(CHANNEL4, 127);

  // Start the sample timer (advance the sampled waveforms)
  sample_timer_start();

  uint16_t current_f = 100;

  while(1)
  {
    HAL_Delay(100);

    current_f += 100;
    current_f = current_f % 4000;

    channel1_state.freq = current_f;
    channel2_state.freq = current_f;
    channel3_state.freq = current_f;
    channel4_state.freq = current_f;
  };
}

/* ========================================================================== */
/*                                                                            */
/*        Main Loop                                                           */
/*                                                                            */
/* ========================================================================== */

int main(void)
{
  // Configure the system's clock.
  SystemClock_Config();

  // Run the checkpoint 2 code
  checkpoint_2();

  // While loop in-case something goes wrong
  while (1)
  { 
    __NOP();
  }
}

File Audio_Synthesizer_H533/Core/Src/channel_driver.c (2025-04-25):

/**
 ******************************************************************************
 * @file    channel_driver.c
 * @brief   Channel Timer Control Interface
 * @author  Adrian Sucahyo
 ******************************************************************************
 * @attention
 *
 * Copyright (c) 2025 Synthetic Bits.
 * All rights reserved.
 *
 * This software is licensed under terms that can be found in the LICENSE file
 * in the root directory of this software component.
 * If no LICENSE file comes with this software, it is provided AS-IS.
 *
 ******************************************************************************
 */

/* Includes ------------------------------------------------------------------*/
#include "main.h"

#include "channel_driver.h"

#include "audio_config.h"
#include "channel_common.h"
#include "config.h"
#include "rcc.h"

/* Private includes ----------------------------------------------------------*/
#include <stdio.h>
#include <string.h>

#include "stm32h5xx_hal.h"

#include "sine_base.h"
#include "trig_base.h"
#include "ramp_base.h"
#include "square_base.h"

#include "attack_base.h"
#include "decay_base.h"

#include "modulation_base.h"

#include "notes.h"

/* Function Prototypes -------------------------------------------------------*/

void channel_enable(channel_t channel);
void channel_disable(channel_t channel);
void channel_set_waveform(channel_t channel, waveforms_t wave);
void channel_volume(channel_t channel, uint8_t volume);

void channel_voice_on(channel_t channel, uint8_t voice);
void channel_voice_off(channel_t channel, uint8_t voice);
void channel_voice_frequency(channel_t channel, uint8_t voice, uint16_t freq);
void channel_voice_modulation(channel_t channel, uint16_t modulation);
void channel_voice_velocity(channel_t channel, uint8_t voice, uint8_t velocity);

static inline void channel_update_CCR(channel_t channel, uint32_t ccr);
static inline void channel_update(volatile channel_state_t *channel);
void channel_update_all();

static void reset_channel(volatile channel_state_t *channel, channel_t channel_num, uint8_t num_voices);
static void channel_timer_gpio_init();
void channel_timer_init();

/* ========================================================================== */
/*                                                                            */
/*    Local Variables Definitions                                             */
/*                                                                            */
/* ========================================================================== */

#define CHANNEL_TIMER_PSC (1 - 1)
#define CHANNEL_TIMER_ARR ((0x1 << 10) - 1) // ~240 kHz (244 kHz)

#define CHANNEL_SAMPLING_VS_ENVELOPE_DIFF (4) // 65536 -> 4096 (RSH 4)
#define CHANNEL_SAMPLING_VS_MODULATION_DIFF (4)

// Define if need less channels for debugging
// #define DEBUG_CHANNELS

// Channel Configuration
#ifdef DEBUG_CHANNELS
#define CHANNEL1_VOICES 4
#define CHANNEL2_VOICES 4
#define CHANNEL3_VOICES 4
#define CHANNEL4_VOICES 4
#define CHANNEL5_VOICES 4
#define CHANNEL6_VOICES 4
#define CHANNEL7_VOICES 4
#define CHANNEL8_VOICES 1
#else
#define CHANNEL1_VOICES 8
#define CHANNEL2_VOICES 8
#define CHANNEL3_VOICES 8
#define CHANNEL4_VOICES 8
#define CHANNEL5_VOICES 8
#define CHANNEL6_VOICES 8
#define CHANNEL7_VOICES 8
#define CHANNEL8_VOICES 1
#endif

volatile channel_state_t channel1_state, channel2_state, channel3_state, channel4_state, channel5_state, channel6_state, channel7_state, channel8_state;

/* ========================================================================== */
/*                                                                            */
/*    Control Functions                                                       */
/*                                                                            */
/* ========================================================================== */

void channel_enable(channel_t channel)
{
  switch (channel)
  {
  case CHANNEL1:
    channel1_state.enable = 1;
    CHANNEL1_4_TIMER->CCER |= TIM_CCER_CC1E;
    break;
  case CHANNEL2:
    channel2_state.enable = 1;
    CHANNEL1_4_TIMER->CCER |= TIM_CCER_CC2E;
    break;
  case CHANNEL3:
    channel3_state.enable = 1;
    CHANNEL1_4_TIMER->CCER |= TIM_CCER_CC3E;
    break;
  case CHANNEL4:
    channel4_state.enable = 1;
    CHANNEL1_4_TIMER->CCER |= TIM_CCER_CC4E;
    break;
  case CHANNEL5:
    channel5_state.enable = 1;
    CHANNEL5_7_TIMER->CCER |= TIM_CCER_CC1E;
    break;
  case CHANNEL6:
    channel6_state.enable = 1;
    CHANNEL5_7_TIMER->CCER |= TIM_CCER_CC2E;
    break;
  case CHANNEL7:
    channel7_state.enable = 1;
    CHANNEL5_7_TIMER->CCER |= TIM_CCER_CC3E;
    break;
  case CHANNEL8:
    channel8_state.enable = 1;
    CHANNEL8_DAC->CR |= DAC_CR_CEN2;
    break;
  default:
    return;
  }
}

void channel_disable(channel_t channel)
{
  switch (channel)
  {
  case CHANNEL1:
    channel1_state.enable = 0;
    CHANNEL1_4_TIMER->CCER &= ~TIM_CCER_CC1E;
    break;
  case CHANNEL2:
    channel2_state.enable = 0;
    CHANNEL1_4_TIMER->CCER &= ~TIM_CCER_CC2E;
    break;
  case CHANNEL3:
    channel3_state.enable = 0;
    CHANNEL1_4_TIMER->CCER &= ~TIM_CCER_CC3E;
    break;
  case CHANNEL4:
    channel4_state.enable = 0;
    CHANNEL1_4_TIMER->CCER &= ~TIM_CCER_CC4E;
    break;
  case CHANNEL5:
    channel5_state.enable = 0;
    CHANNEL5_7_TIMER->CCER &= ~TIM_CCER_CC1E;
    break;
  case CHANNEL6:
    channel6_state.enable = 0;
    CHANNEL5_7_TIMER->CCER &= ~TIM_CCER_CC2E;
    break;
  case CHANNEL7:
    channel7_state.enable = 0;
    CHANNEL5_7_TIMER->CCER &= ~TIM_CCER_CC3E;
    break;
  case CHANNEL8:
    channel8_state.enable = 0;
    CHANNEL8_DAC->CR &= ~DAC_CR_CEN2;
    break;
  default:
    return;
  }
}
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

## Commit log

2025-03-24 Wrote the initial UART code
2025-03-25 Wrote a function to easily initialize the micro-controller's LEDs
2025-03-25 Wrote a test for both UART1 and UART2 and attempted to get them working (both broken)
    [main.c, uart.c]
2025-03-25 Basic test case for UART1 as it still isn't working
2025-03-26 Added support for UART3 and tested that it works as intended
2025-03-26 Renamed testUART() to testUART1_2() as well as added header comments to uart.h
2025-03-26 Wrote the sample timer header
2025-03-26 Wrote preliminary implementation of the sample timer
2025-03-29 Preliminary Schematic Layout
    [Low_Pass_Filter.SchDoc, MIDI_Synthesizer.SchDoc, MIDI_Synthesizer_PCB.PcbDoc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]
2025-03-29 Added additional pin definitions to config
2025-03-31 More updates to schematic
    [MIDI_Synthesizer.SchDoc, MIDI_Synthesizer_PCB.PrjPcb]
2025-04-01 Schematic Complete
    [Low_Pass_Filter.SchDoc, MIDI_Synthesizer.SchDoc]
2025-04-01 Footprints Complete
    [Low_Pass_Filter.SchDoc, MIDI_Synthesizer.SchDoc, MIDI_Synthesizer_PCB.PcbDoc]
2025-04-02 Removed uart test code (should be in main instead)
2025-04-02 Fixed HAL toggling leds
    [midi.c]
2025-04-02 Rewrote uart.h to follow STM code standards
2025-04-02 Updated PCB
    [Low_Pass_Filter.SchDoc, MIDI_Synthesizer.SchDoc, MIDI_Synthesizer_PCB.PcbDoc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]
2025-04-02 Bugfixes to the first checkpoint
    [main.c, midi.c]
2025-04-03 Disabled interrupts in UART processing code of checkpoint 1
2025-04-03 More PCB Layout Progress
    [Low_Pass_Filter.SchDoc, MIDI_Synthesizer.SchDoc, MIDI_Synthesizer_BOM.xlsx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]
2025-04-03 Begun the process of moving all of the pin definitions to one file
2025-04-03 Added pin definitions for the timer channels (F072, exact pins TBD)
2025-04-04 Layout rev 1 coplete
    [MIDI_Synthesizer_PCB.PrjPcb]
2025-04-04 Completed Layout
    Completed Layout
    [Low_Pass_Filter.SchDoc, MIDI_Synthesizer.SchDoc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]
2025-04-04 Generated Gerbers
    [MIDI_Synthesizer_PCB.GBL, MIDI_Synthesizer_PCB.GBO, MIDI_Synthesizer_PCB.GBP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]
2025-04-09 Gerber Files Generated
    [MIDI_Synthesizer_PCB.GBL, MIDI_Synthesizer_PCB.GBO, MIDI_Synthesizer_PCB.GBP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]
2025-04-09 renamed get_mid to set_midi and added setup_midi to setup timers and channles
2025-04-09 Added a function that allows the user to easily print to a UART console
2025-04-16 Reformatted how the samples are stored in their header files
2025-04-17 Rewrote channel driver for FM and Voices
2025-04-17 Bugfixes and tests for the UART code
    [main.c, uart.c]
2025-04-20 Successfully tested USER_UART w/ and w/o interrupts
2025-04-20 Modifications to UART logic
2025-04-20 Successfully tested MIDI_UART w/o interrupts
2025-04-20 Modified config.h to clearly tell what pin goes to where
2025-04-20 Successfully tested MIDI_UART w/ interrupts
2025-04-20 Commented out the UART tests
2025-04-20 Updated Necessary Fixes for Audio + Formatting
    [channel_driver.c, main.c, rcc.c]
2025-04-21 Slight Modification to current demo
2025-04-23 modulation, key pressure, key on and off voice number map
    added modulation call (waiting for updated function)
    added key pressure function call
    added key on and off voice number map
2025-04-23 Updated Fixes to sample timer
    [sample_timer.c]
2025-04-23 Commented out noise_timer.c as it is failing to compile
    [noise_timer.c]
2025-04-23 Added Noise Baseline - currently not working
    [channel_driver.c, main.c]
2025-04-23 added midi_urart_test, added default case to midi.c
2025-04-24 Waveforms genreate and UART/MIDI Setup
2025-04-24 added imgs of board and diagrams
2025-04-24 moved imgs to the new location and added info about the board to the readme
2025-04-24 Tried to fix the active voice issue by checking our ADSR states
    [channel_driver.c, main.c, midi.c]
2025-04-25 added note off check for velocity == 0 in note ON event
2025-04-25 debug leds
